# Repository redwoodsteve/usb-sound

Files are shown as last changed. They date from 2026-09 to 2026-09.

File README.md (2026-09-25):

# usb-sound
USB sound card for ham radio

## Features
 - Adjustable input attenuation (for mic in and left channel)
 - Configurable OMTP jack (TRRS; left, right, mic, gnd)
 - PTT circuit (pulls down to gnd)
 - (Optional) Mini-DIN8 Port compatible with Xiegu transceivers (designed for the G90)
 - CM108B IC

## Technical Details
There is a massive test point (marked "PTT") so you can solder whatever you want to control on.
> [!NOTE]
> The PTT pin is shorted to GND when activated, with no current limiting or decoupling.
There are two audio jacks. By default, they are configured as:
 - OUT: T=Left out, S=GND
 - IN: T=Input, S=GND
The OUT jack is configurable (through two solder jumpers on the back) for an OMTP style:
 - T=Left out
 - R1=Right out
 - R2=Mic in
 - S=GND
There are two 10k potentiometers configured as voltage dividers to attenuate the left channel and the mic input.
They each have a 1k resistor connected from wiper to ground to make them feel more logarithmic.

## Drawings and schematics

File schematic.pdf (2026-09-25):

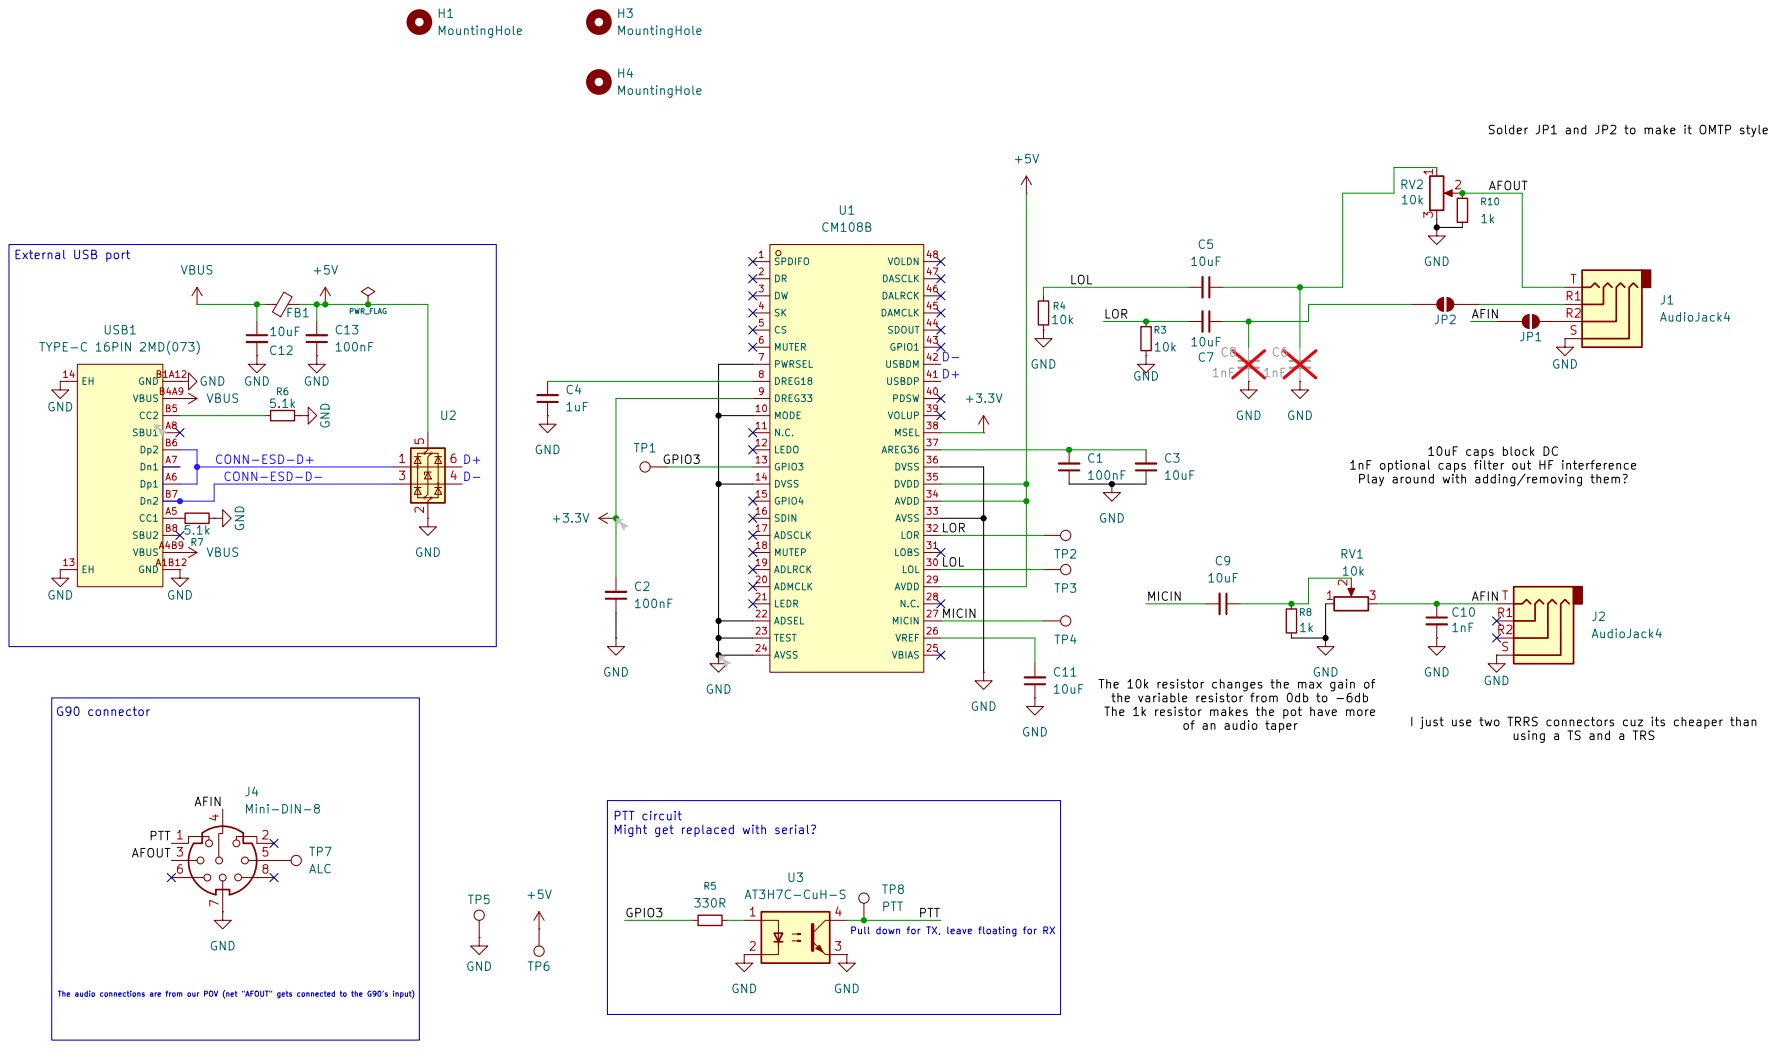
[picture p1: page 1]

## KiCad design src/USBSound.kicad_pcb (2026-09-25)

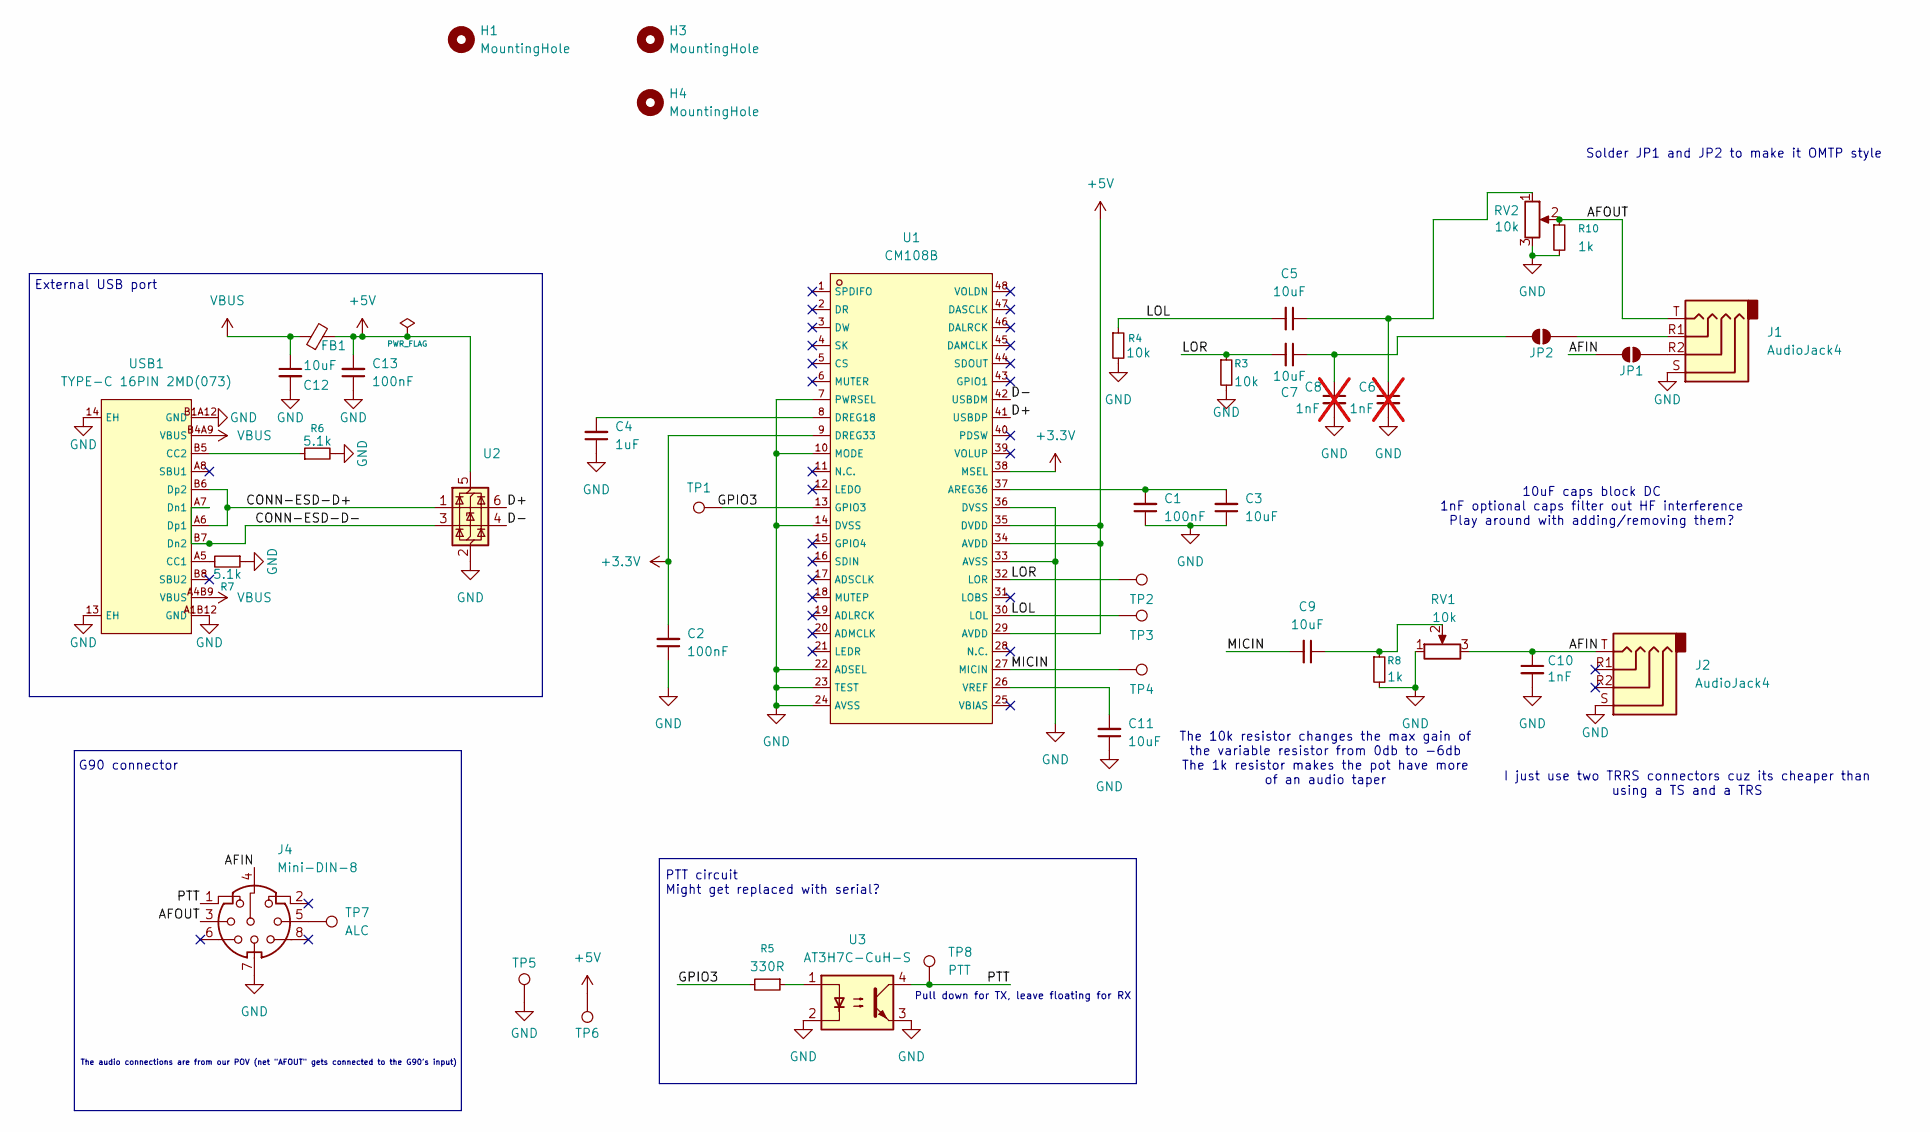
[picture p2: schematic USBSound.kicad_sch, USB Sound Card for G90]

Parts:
C1, C2, C13: 100nF; C_0805_2012Metric; LCSC C5137467
C3, C5, C7, C9, C11, C12: 10uF; C_0805_2012Metric; LCSC C1713
C4: 1uF; C_0805_2012Metric; LCSC C28323
C6, C8: 1nF; C_0805_2012Metric; LCSC C94121; not fitted
C10: 1nF; C_0805_2012Metric; LCSC C94121
FB1: MPZ2012S101AT000; C_0805_2012Metric; LCSC C15957
H1, H3, H4: MountingHole; MountingHole_3mm
J1, J2: AudioJack4; Jack_3.5mm_KoreanHropartsElec_PJ-320D-4A_Horizontal; LCSC C95562
J4: Mini-DIN-8; C6456814_CONN-TH_5749267-1-1; LCSC C6456814
JP1, JP2: SolderJumper_2_Open; SolderJumper-2_P1.3mm_Open_RoundedPad1.0x1.5mm
R3, R4: 10k; R_0805_2012Metric; LCSC C2907219
R5: 330R; R_0805_2012Metric; LCSC C2930157
R6, R7: 5.1k; R_0805_2012Metric; LCSC C84375
R8, R10: 1k; R_0805_2012Metric; LCSC C2907219
RV1, RV2: 10k; Potentiometer_Bourns_3296W_Vertical; LCSC C118954
TP1: GPIO3; TestPoint_Pad_D1.5mm
TP2: LOR; TestPoint_Pad_D1.5mm
TP3: LOL; TestPoint_Pad_D1.5mm
TP4: MICIN; TestPoint_Pad_D1.5mm
TP5, TP6: TestPoint; TestPoint_Pad_D1.5mm
TP7: ALC; TestPoint_Pad_D1.5mm
TP8: PTT; TestPoint_Pad_D2.5mm
U1: CM108B; C371347_LQFP-48_L7_0-W7_0-P0_50-LS9_0-BL; LCSC C371347
U2: USBLC6-2SC6; SOT-23-6; LCSC C2827654
U3: AT3H7C-CuH-S; SSOP-4_4.4x2.6mm_P1.27mm; LCSC C20612661
USB1: TYPE-C 16PIN 2MD(073); C2765186_USB-C-SMD_TYPE-C-16PIN-2MD-073; LCSC C2765186

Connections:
+3.3V: C2.2, U1.9 (DREG33), U1.38 (MSEL)
+5V: C13.2, FB1.2, TP6.1 (1_1), U1.29 (AVDD), U1.34 (AVDD), U1.35 (DVDD), U2.5 (VBUS)
/AFIN: C10.1, J2.T, J4.4, JP1.1 (A), RV1.3
/AFOUT: J1.T, J4.3, R10.1, RV2.2
/CONN-ESD-D+: U2.1 (I/O1), USB1.A6 (Dp1), USB1.B6 (Dp2)
/CONN-ESD-D-: U2.3 (I/O2), USB1.A7 (Dn1), USB1.B7 (Dn2)
/D+: U1.41 (USBDP), U2.6 (I/O1)
/D-: U1.42 (USBDM), U2.4 (I/O2)
/GPIO3: R5.2, TP1.1 (1_1), U1.13 (GPIO3)
/LOL: C5.2, R4.1, TP3.1 (1_1), U1.30 (LOL)
/LOR: C7.2, R3.1, TP2.1 (1_1), U1.32 (LOR)
/MICIN: C9.2, TP4.1 (1_1), U1.27 (MICIN)
/PTT: J4.1, TP8.1 (1_1), U3.4
GND: C1.1, C2.1, C3.1, C4.1, C6.2, C8.2, C10.2, C11.1, C12.2, C13.1, J1.S, J2.S, J4.7, R3.2, R4.2, R6.2, R7.1, R8.2, R10.2, RV1.1, RV2.3, TP5.1 (1_1), U1.7 (PWRSEL), U1.10 (MODE), U1.14 (DVSS), U1.22 (ADSEL), U1.23 (TEST), U1.24 (AVSS), U1.33 (AVSS), U1.36 (DVSS), U2.2 (GND), U3.2, U3.3, USB1.13 (EH), USB1.14 (EH), USB1.A1B12 (GND), USB1.B1A12 (GND)
unnamed: C5.1, C6.1, RV2.1
unnamed: C9.1, R8.1, RV1.2
unnamed: J4.5, TP7.1 (1_1)
unnamed: J1.R2, JP1.2 (B)
unnamed: C7.1, C8.1, JP2.1 (A)
unnamed: J1.R1, JP2.2 (B)
unnamed: R5.1, U3.1
unnamed: C1.2, C3.2, U1.37 (AREG36)
unnamed: C4.2, U1.8 (DREG18)
unnamed: C11.2, U1.26 (VREF)
unnamed: R7.2, USB1.A5 (CC1)
unnamed: R6.1, USB1.B5 (CC2)
VBUS: C12.1, FB1.1, USB1.A4B9 (VBUS), USB1.B4A9 (VBUS)

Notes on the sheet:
External USB port
Solder JP1 and JP2 to make it OMTP style
I just use two TRRS connectors cuz its cheaper than using a TS and a TRS
10uF caps block DC 1nF optional caps filter out HF interference Play around with adding/removing them?
G90 connector
PTT circuit Might get replaced with serial?
Pull down for TX, leave floating for RX
The audio connections are from our POV (net "AFOUT" gets connected to the G90's input)
The 10k resistor changes the max gain of the variable resistor from 0db to -6db The 1k resistor makes the pot have more of an audio taper

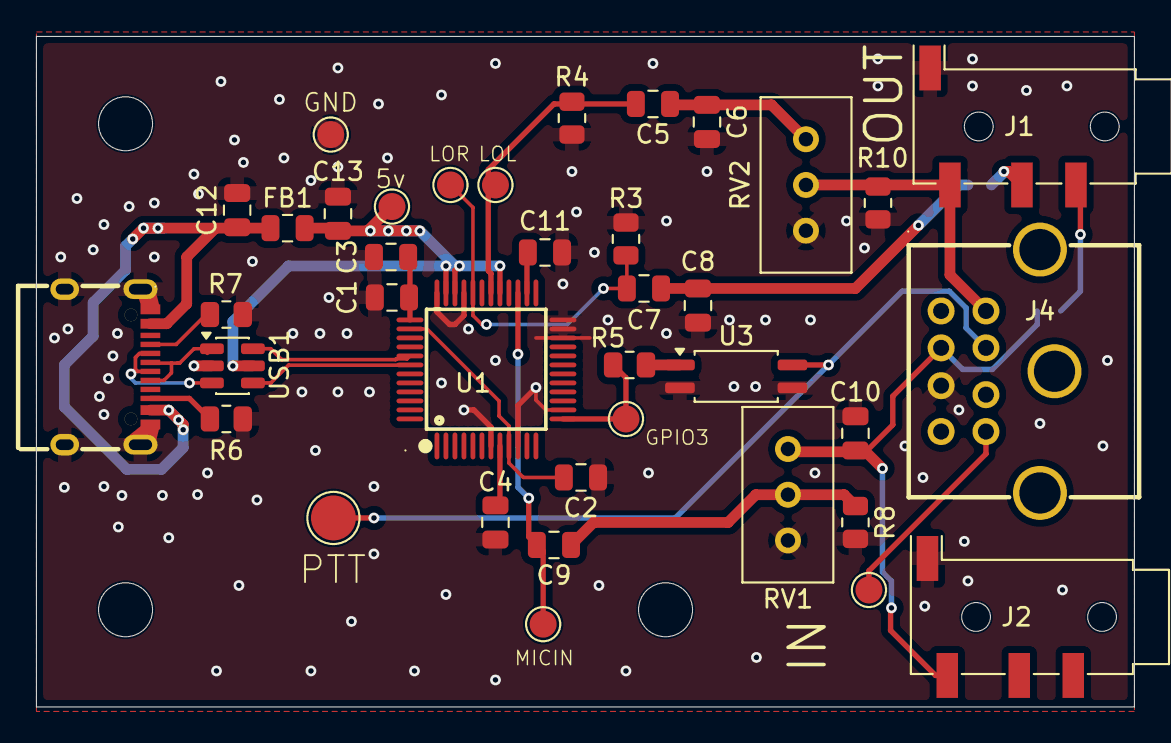
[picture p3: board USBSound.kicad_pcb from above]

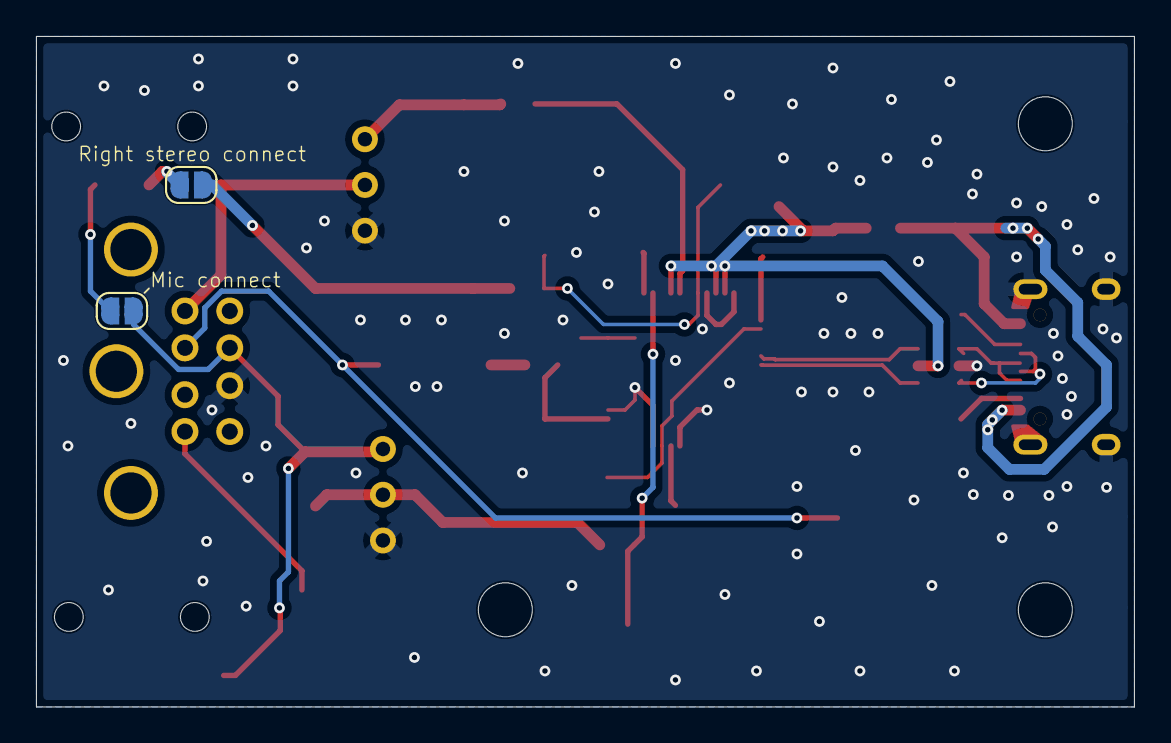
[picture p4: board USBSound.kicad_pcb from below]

Board: 2 copper layers, 61.0 x 37.2 mm, 43 parts (2 on the bottom side), 27 nets.

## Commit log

2026-09-25 Remove 10k attenuation resistor from potentiometers
    [USBSound.kicad_pcb, USBSound.kicad_sch]
2026-09-25 Clarify potentiometer configuration in README
    Removed redundant explanation about the 10k resistors in series with the potentiometers.
